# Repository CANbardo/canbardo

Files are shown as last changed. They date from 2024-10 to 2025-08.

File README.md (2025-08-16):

# CANbardo

CANbardo is an open hardware Universal Serial Bus (USB) to Controller
Area Network (CAN) adapter board. It is designed to be compatible with
the open source
[CANnectivity](https://github.com/CANnectivity/cannectivity) firmware.

CANbardo is licensed under the [CERN-OHL-P-2.0 license](LICENSE).

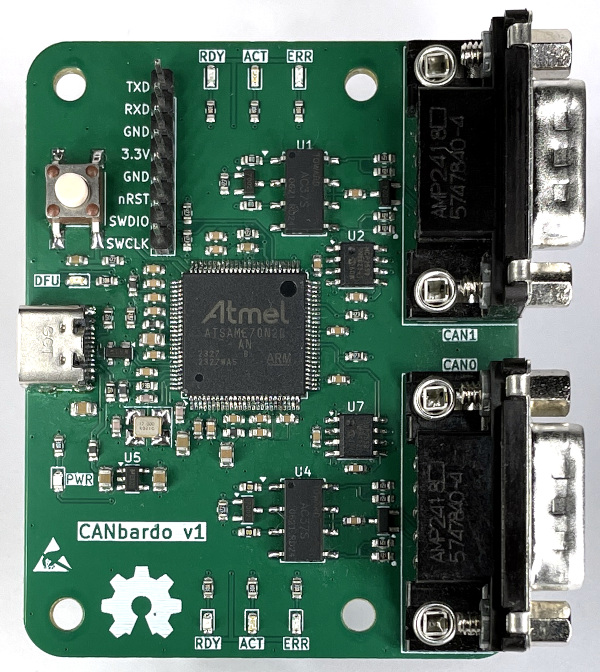
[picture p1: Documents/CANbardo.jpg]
CANbardo


## Hardware Features

The CANbardo board provides the following features:

- Atmel SAME70N20B microcontroller
- 12 MHz 10 ppm crystal
- CAN classic support
- CAN FD (flexible data rate) support
- Fast-speed and Hi-speed USB 2.0 support (USB-C connector)
- Two independent CAN channels (DB-9M connectors)
- 2 x GPIO-controlled MCP2558FD CAN transceivers
- 2 x GPIO-controlled 120 ohm CAN bus termination resistors
- GPIO-controlled LEDs:
  - 2 x CAN channel state LEDs (green)
  - 2 x CAN channel activity LEDs (yellow)
  - 2 x CAN channel error LEDs (red)
  - 1 x Device Firmware Upgrade (DFU) LED (yellow)
- Power LED (green)
- Device Firmware Upgrade (DFU) push button
- Serial Wire Debug (SWD) and UART (3V3) available on header

## Firmware Support

The CANbardo board is supported by the following firmware:

- [Zephyr RTOS](https://docs.zephyrproject.org/latest/boards/others/canbardo/doc/index.html)
- [CANnectivity](https://github.com/CANnectivity/cannectivity)

## Enclosure

An [OpenSCAD](https://openscad.org) model for an acyllic enclosure is
available under the [Enclosure](Enclosure) folder. This model is
designed to laser cut in 2 mm clear acrylic plates and fitted to the
CANbardo board using eight M3x6 BH insex screws and four M3x8 threaded
standoffs.

## Design Documentation

The following design documentation is available:

- [Schematic](Documents/CANbardo_Schematic.pdf)
- [Layout](Documents/CANbardo-Layout.pdf)
- [3D model](Documents/CANbardo.step)
- [KiCad files](Kicad_8_files)
- [Fabrication files](Fabrication_files)
- [3D view](Documents/3D_view.png)
- [Enclosure](Enclosure)

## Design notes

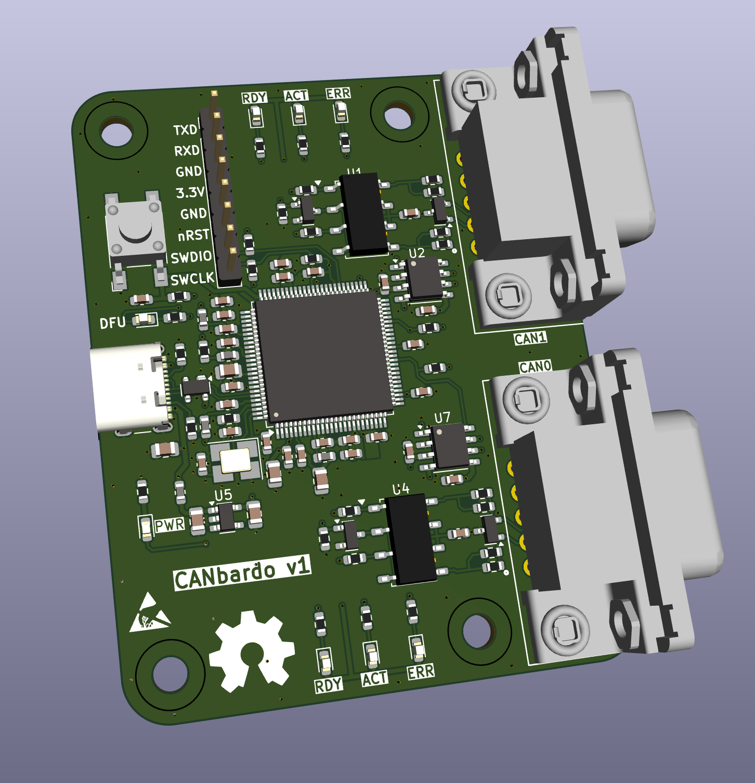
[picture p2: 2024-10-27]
Documents/3D_view.png

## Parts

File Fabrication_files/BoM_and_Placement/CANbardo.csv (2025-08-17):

Id | Designator | Footprint | Quantity | Designation | Supplier and ref
1 | C12,C14,C6 | C_0603_1608Metric | 3 | 10p
2 | J1 | USB_C_Receptacle_GCT_USB4105-xx-A_16P_TopMnt_Horizontal | 1 | USB_C_Receptacle_USB2.0
3 | J5 | PinHeader_1x08_P2.54mm_Vertical_zigzag | 1 | Conn_01x08_Pin
4 | R5,R11,R12 | R_0603_1608Metric | 3 | 2.7k
5 | R13,R16,R32 | R_0603_1608Metric | 3 | 390R
6 | R14,R19 | R_0603_1608Metric | 2 | 620R
7 | R15,R1,R9,R18 | R_0603_1608Metric | 4 | 4.7k
8 | U1,U4 | SOP-8GW_4.4x9.4mm_P2.54mm | 2 | AC37S
9 | C24,C33,C25,C18,C31,C7,C8,C22,C11,C23,C4,C20,C13,C17,C9,C21,C32,C26,C1,C19,C28,C29 | C_0603_1608Metric | 22 | 100n
10 | C5,C3,C2,C30 | C_0805_2012Metric | 4 | 1u
11 | R24,R22,R23,R20,R28,R26,R25,R27 | R_0603_1608Metric | 8 | 120R
12 | R2,R7,R6,R10 | R_0603_1608Metric | 4 | 47k
13 | FB4,FB5,FB3,FB2 | L_0603_1608Metric | 4 | blm18pg471sn1
14 | C16,C15 | C_0805_2012Metric | 2 | 4.7u
15 | D3,D10,D6 | LED_0603_1608Metric | 3 | LED 0603 Yellow
16 | R8,R17,R21,R29 | R_0603_1608Metric | 4 | 1k
17 | U5 | SOT-23-5 | 1 | AP2112K-3.3
18 | Q2,Q1 | SOT-23 | 2 | 2N7002
19 | D1,D5,D2 | LED_0603_1608Metric | 3 | LED 0603 Green
20 | D9,D8 | SOT-23 | 2 | NUP2105L
21 | C27,C10 | C_0603_1608Metric | 2 | 47n
22 | R3,R4 | R_0603_1608Metric | 2 | 5.1k
23 | J4,J3 | CONN9_5747840-4_TEC | 2 | DE9_Plug_MountingHoles
24 | R30 | R_0603_1608Metric | 1 | 5.62k
25 | R31 | R_0603_1608Metric | 1 | 2.2R
26 | SW1 | SW_SMD_Tactile_4pin | 1 | FSM4JSMAATR.
27 | FB1 | L_0603_1608Metric | 1 | 120@100MHz
28 | D4,D7 | LED_0603_1608Metric | 2 | LED 0603 Red
29 | Y1 | Crystal_SMD_3225-4Pin_3.2x2.5mm_HandSoldering | 1 | LFXTAL054208RL3K
30 | U2,U7 | SOIC-8_3.9x4.9mm_P1.27mm | 2 | MCP2558FD-xSN
31 | U13 | LQFP-100_14x14mm_P0.5mm | 1 | ATSAME70N20B-AN
32 | D11 | SOT-143 | 1 | PRTR5V0U2X

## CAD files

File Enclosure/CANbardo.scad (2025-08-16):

// Rendering
$fn = 100;

// Plate thickness
thickness = 2;

module plate(screw_d = 3.5) {
    width = 56;
    height = 70;
    rounding = 5;

    difference() {
        translate([rounding, rounding, 0]) {
            minkowski() {
                square(size = [width - 2 * rounding, height - 2 * rounding], center = false);
                circle(r = rounding);
            }
        }

        /* Screw holes */
        for (x = [5, 38]) {
            for (y = [5, 65]) {
                offset_x = x;
                offset_y = y;
                translate([offset_x, offset_y, 0]) {
                    circle(d = screw_d);
                }
            }
        }
    }
}

module plate_bottom() {
    rounding = 1;

    difference() {
        plate();

        /* DB-9M connector shield solder pads */
        for (y = [4, 29, 41, 66]) {
            translate([46.5, y, 0]) {
                circle(d = 5);
            }
        }

        /* DB-9M connector pin solder pads */
        for (y = [11, 48]) {
            translate([45.5 - rounding, y - rounding, 0]) {
                minkowski() {
                    square(size = [6 - 2 * rounding, 15 - 2 * rounding], center = false);
                    circle(r = rounding);
                }
            }
        }

        /* Pin header solder pads */
        translate([16.25 - rounding, 47 - rounding, 0]) {
            minkowski() {
                square(size = [3 - 2 * rounding, 22 - 2 * rounding], center = false);
                circle(r = rounding);
            }
        }
    }
}

module plate_bottom_3d() {
    linear_extrude(height = thickness) {
        plate_bottom();
    }
}

module plate_top() {
    rounding = 1;

    difference() {
        plate();

        /* DFU button */
        translate([6, 52, 0]) {
            circle(d = 4);
        }

        /* DB-9M connectors */
        for (y = [16.5, 53.5]) {
            translate([50, y, 0]) {
                square([13, 18], center = true);
            }
            translate([55, y, 0]) {
                square([12, 33], center = true);
            }
        }

        /* Pin header */
        translate([16.25 - rounding, 47 - rounding, 0]) {
            minkowski() {
                square(size = [3 - 2 * rounding, 22 - 2 * rounding], center = false);
                circle(r = rounding);
            }
        }
    }
}

module plate_top_3d() {
    linear_extrude(height = thickness) {
        plate_top();
    }
}

module model_2d() {
    plate_bottom();

    translate([60, 0, 0]) {
        plate_top();
    }
}

module model_3d() {
    import("CANbardo.stl");

    translate([0, 0, -1 * thickness]) {
        %plate_bottom_3d();
    }

    translate([0, 0, 1.6 + 6]) {
        %plate_top_3d();
    }
}

3d = $preview;

if (3d) {
    model_3d();
} else {
    model_2d();
}

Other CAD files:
Enclosure/CANbardo.dxf

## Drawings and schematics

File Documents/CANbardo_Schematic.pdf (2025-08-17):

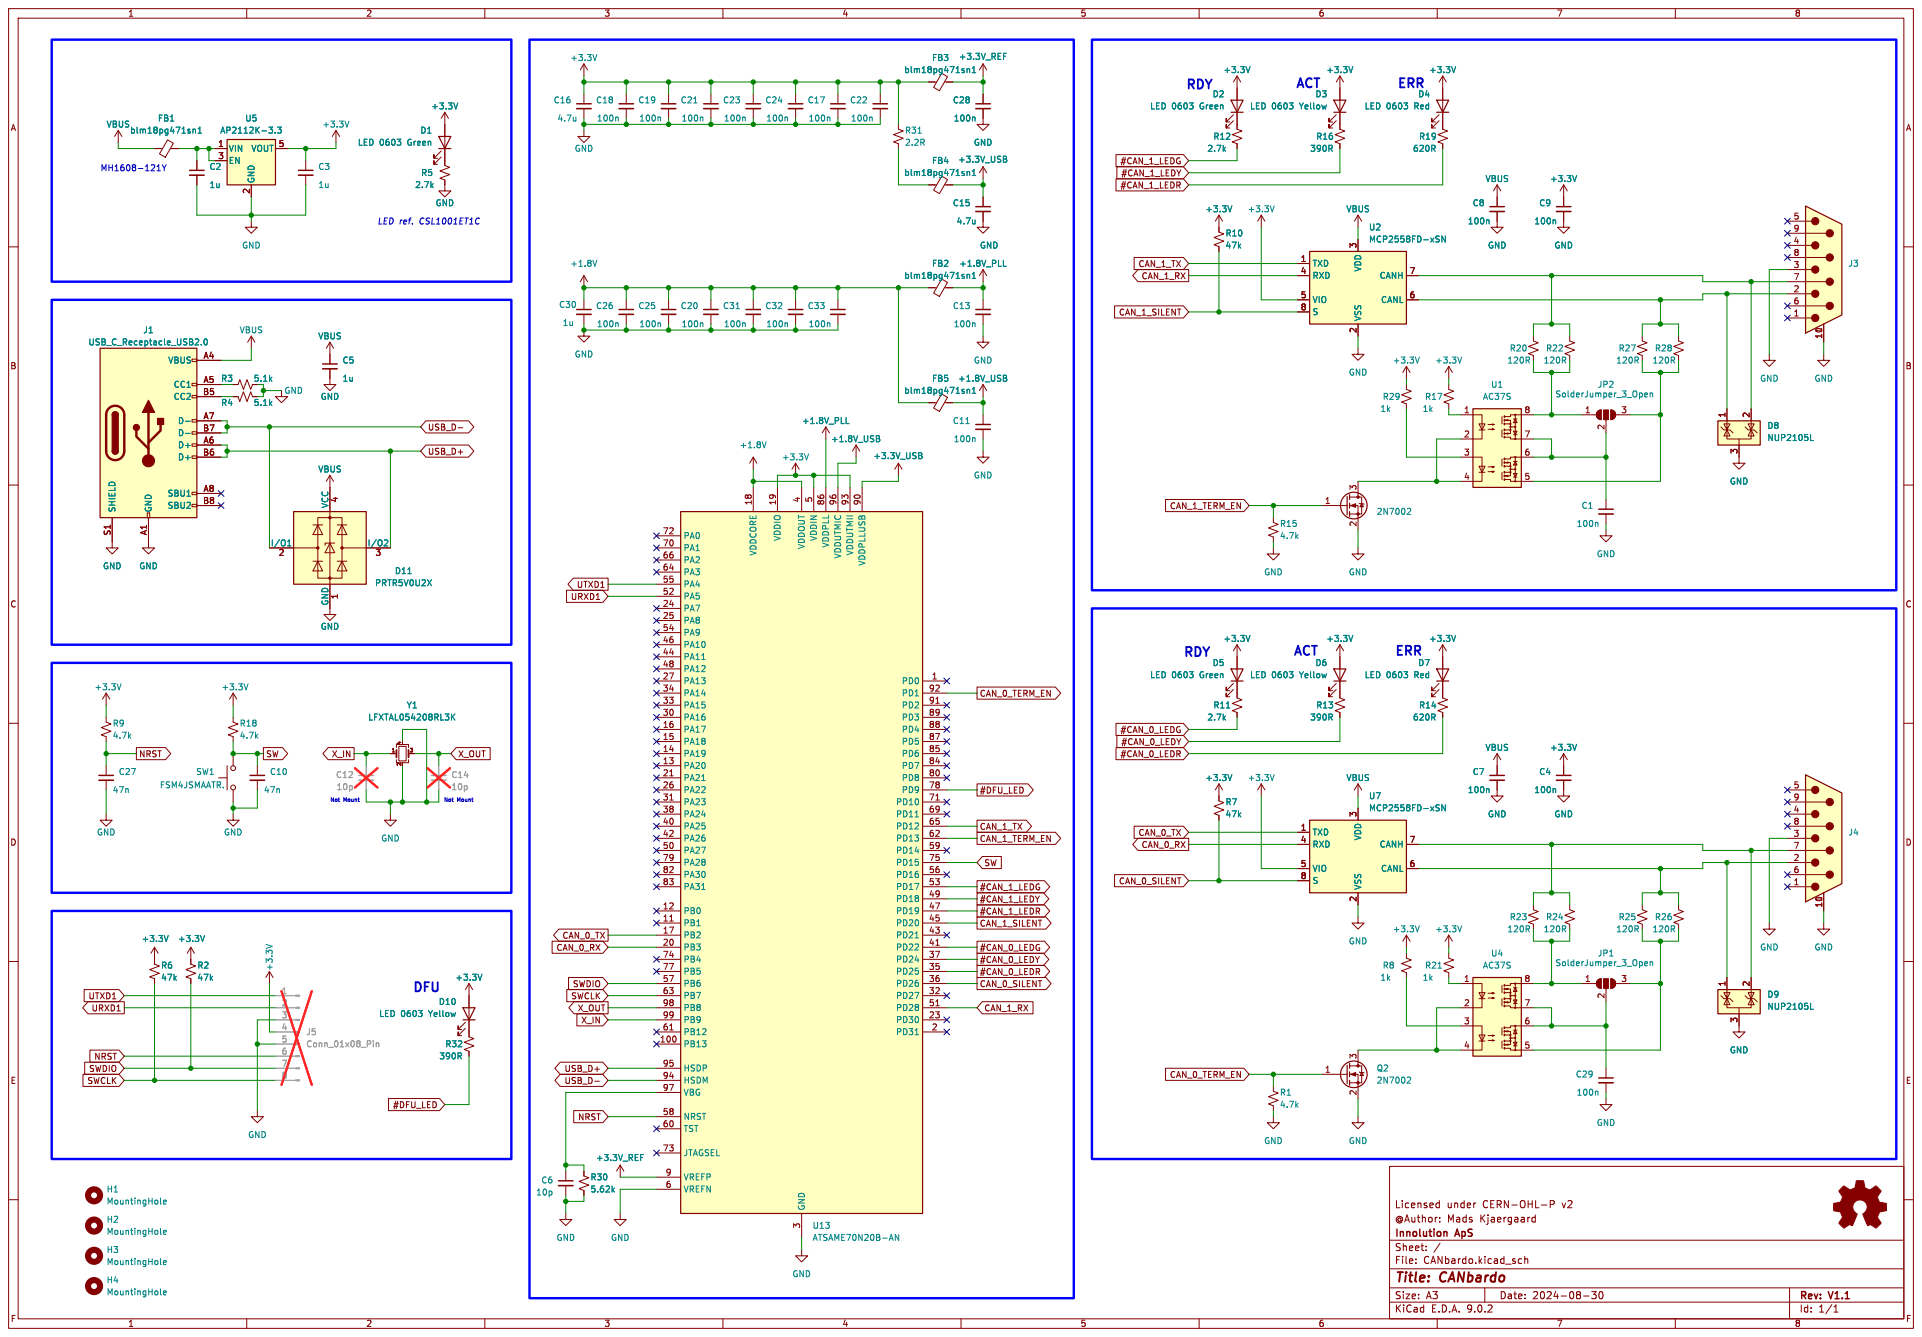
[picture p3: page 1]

PA0 72 PA1 70 PA2 66 PA3 64 PA4 55 PA5 52 PA7 24 PA8 25 PA9 54 PA10 46 PA11 44 PA12 48 PA13 27 PA14 34 PA15 33 PA16 30 PA17 16 PA18 15 PA19 14 PA20 13 PA21 21 PA22 26 PA23 31 PA24 38 PA25 40 PA26 42 PA27 50 PA28 79 PA30 82 PA31 83 PB0 12 PB1 11 PB2 17 PB3 20 PB4 74 PB5 77 PB6 57 PB7 63 PB8 98 PB9 99 PB12 61 PB13 100 HSDP 95 HSDM 94 VBG 97 NRST 58 TST 60

5 VDDPLL 86 VDDUTMIC 96 VDDUTMII 93 VDDPLLUSB 90 PD0 1 PD1 92 PD2 91 PD3 89 PD4 88 PD5 87 PD6 85 PD7 84 PD8 80 PD9 78 PD10 71 PD11 69 PD12 65 PD13 62 PD14 59 PD15 75 PD16 56 PD17 53 PD18 49 PD19 47 PD20 45 PD21 43 PD22 41 PD24 37 PD25 35 PD26 36 PD27 32 PD28 51 PD30 23 PD31 2 U13 ATSAME70N20B-AN

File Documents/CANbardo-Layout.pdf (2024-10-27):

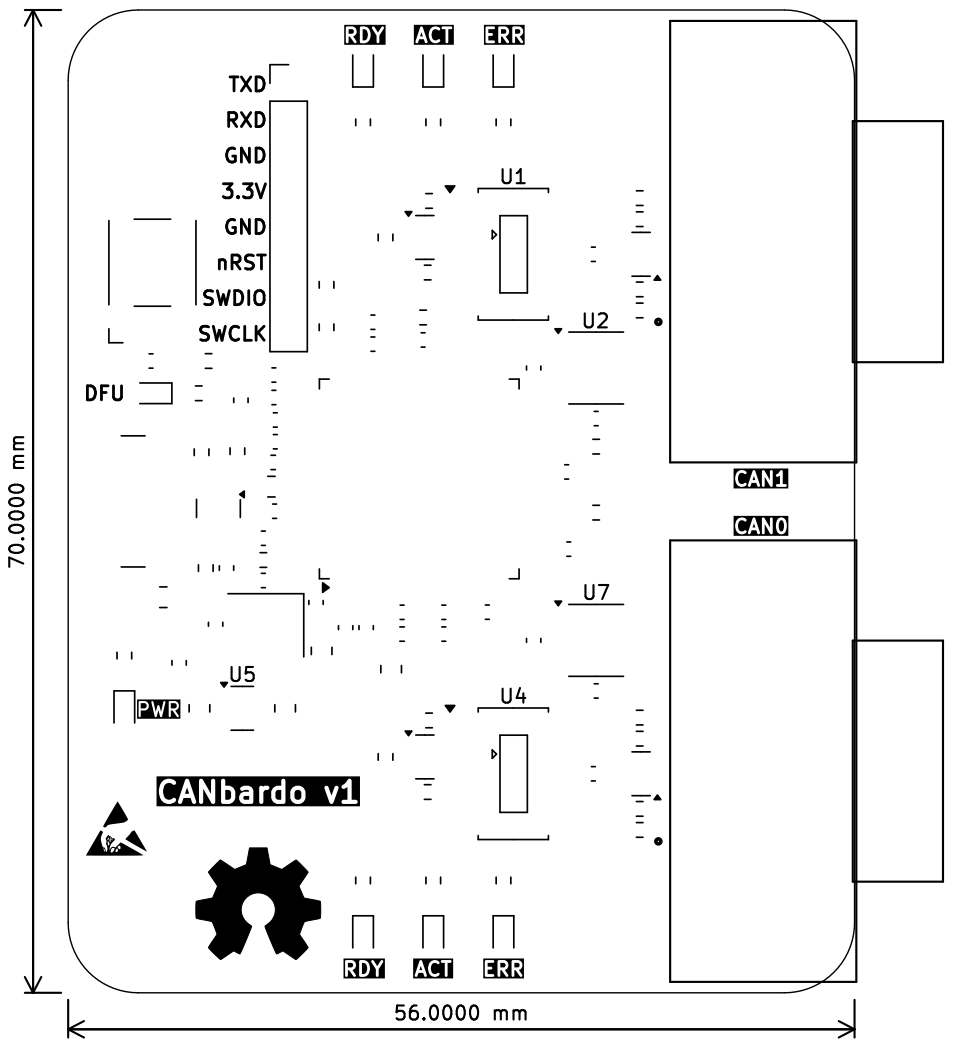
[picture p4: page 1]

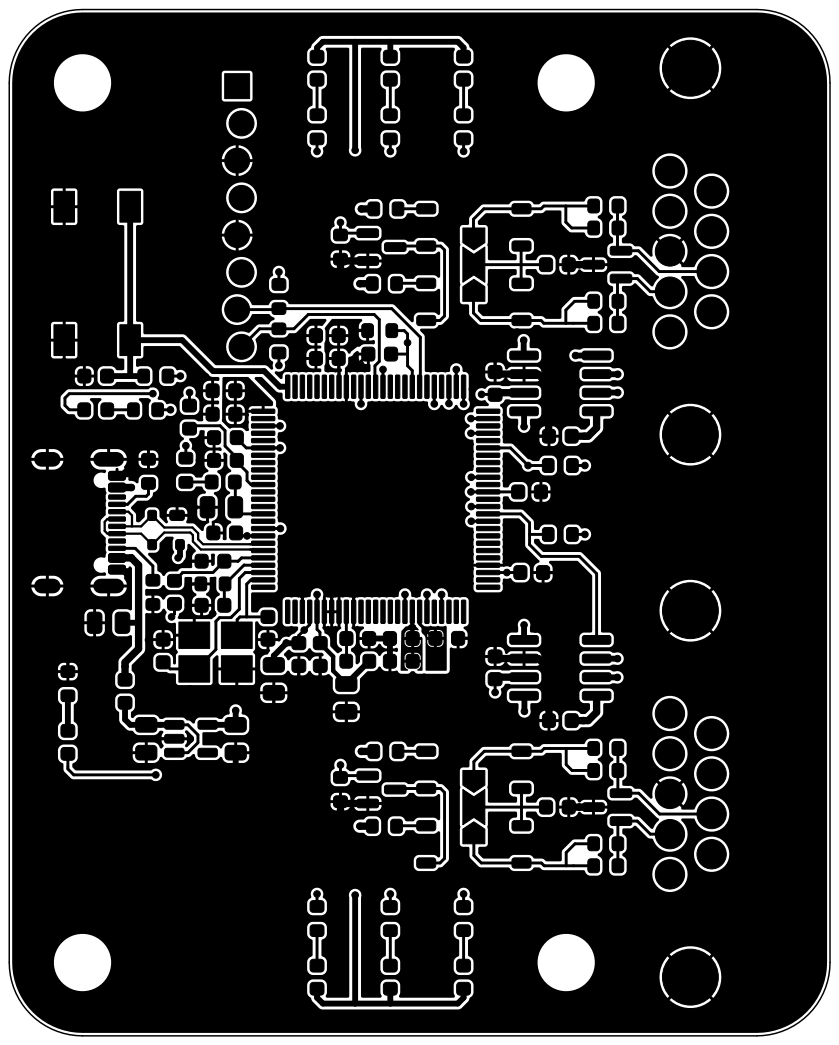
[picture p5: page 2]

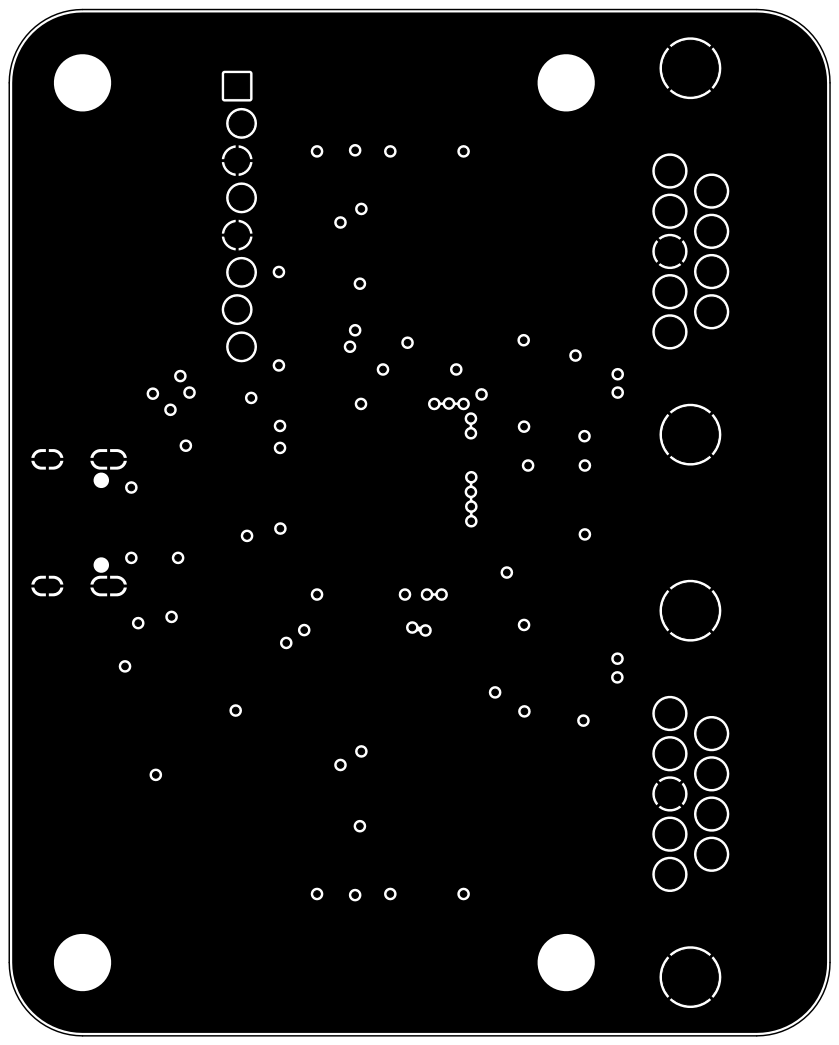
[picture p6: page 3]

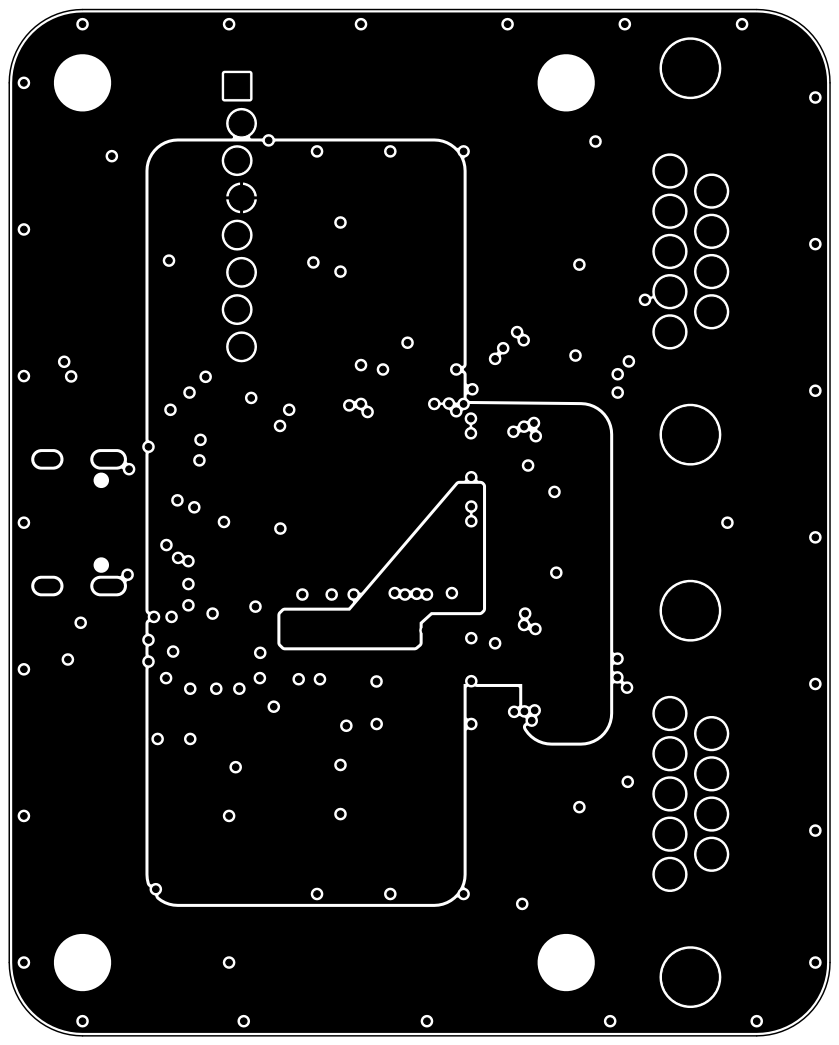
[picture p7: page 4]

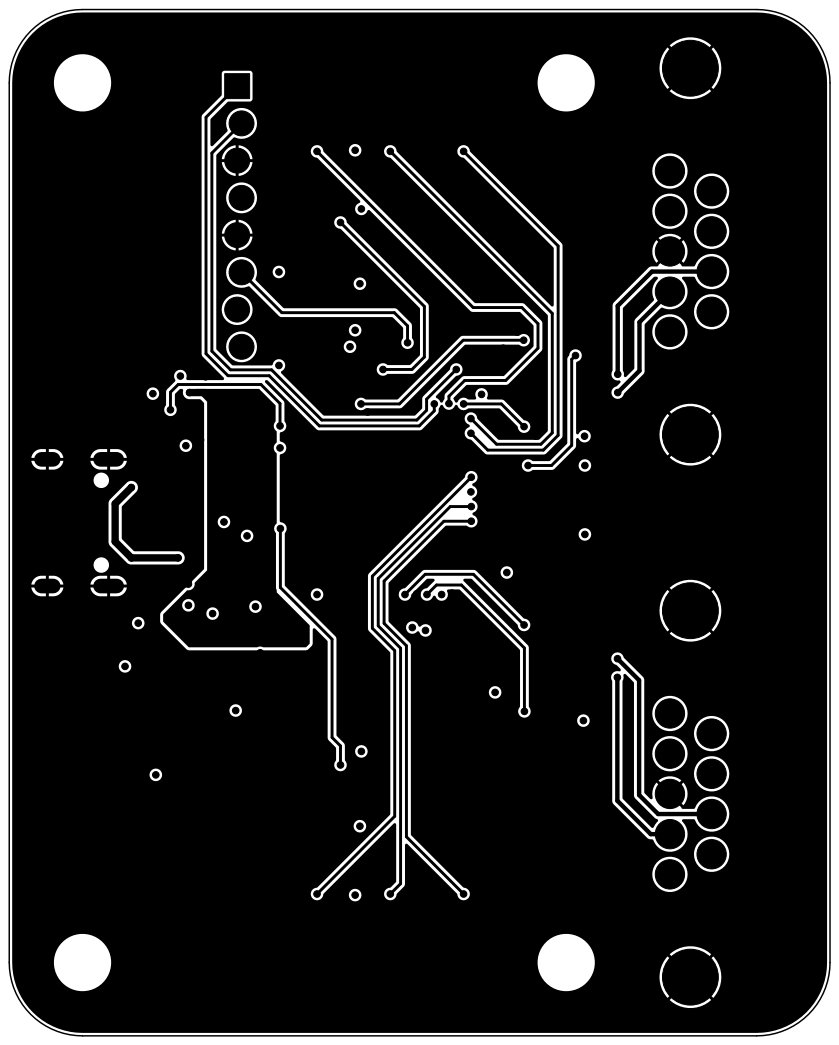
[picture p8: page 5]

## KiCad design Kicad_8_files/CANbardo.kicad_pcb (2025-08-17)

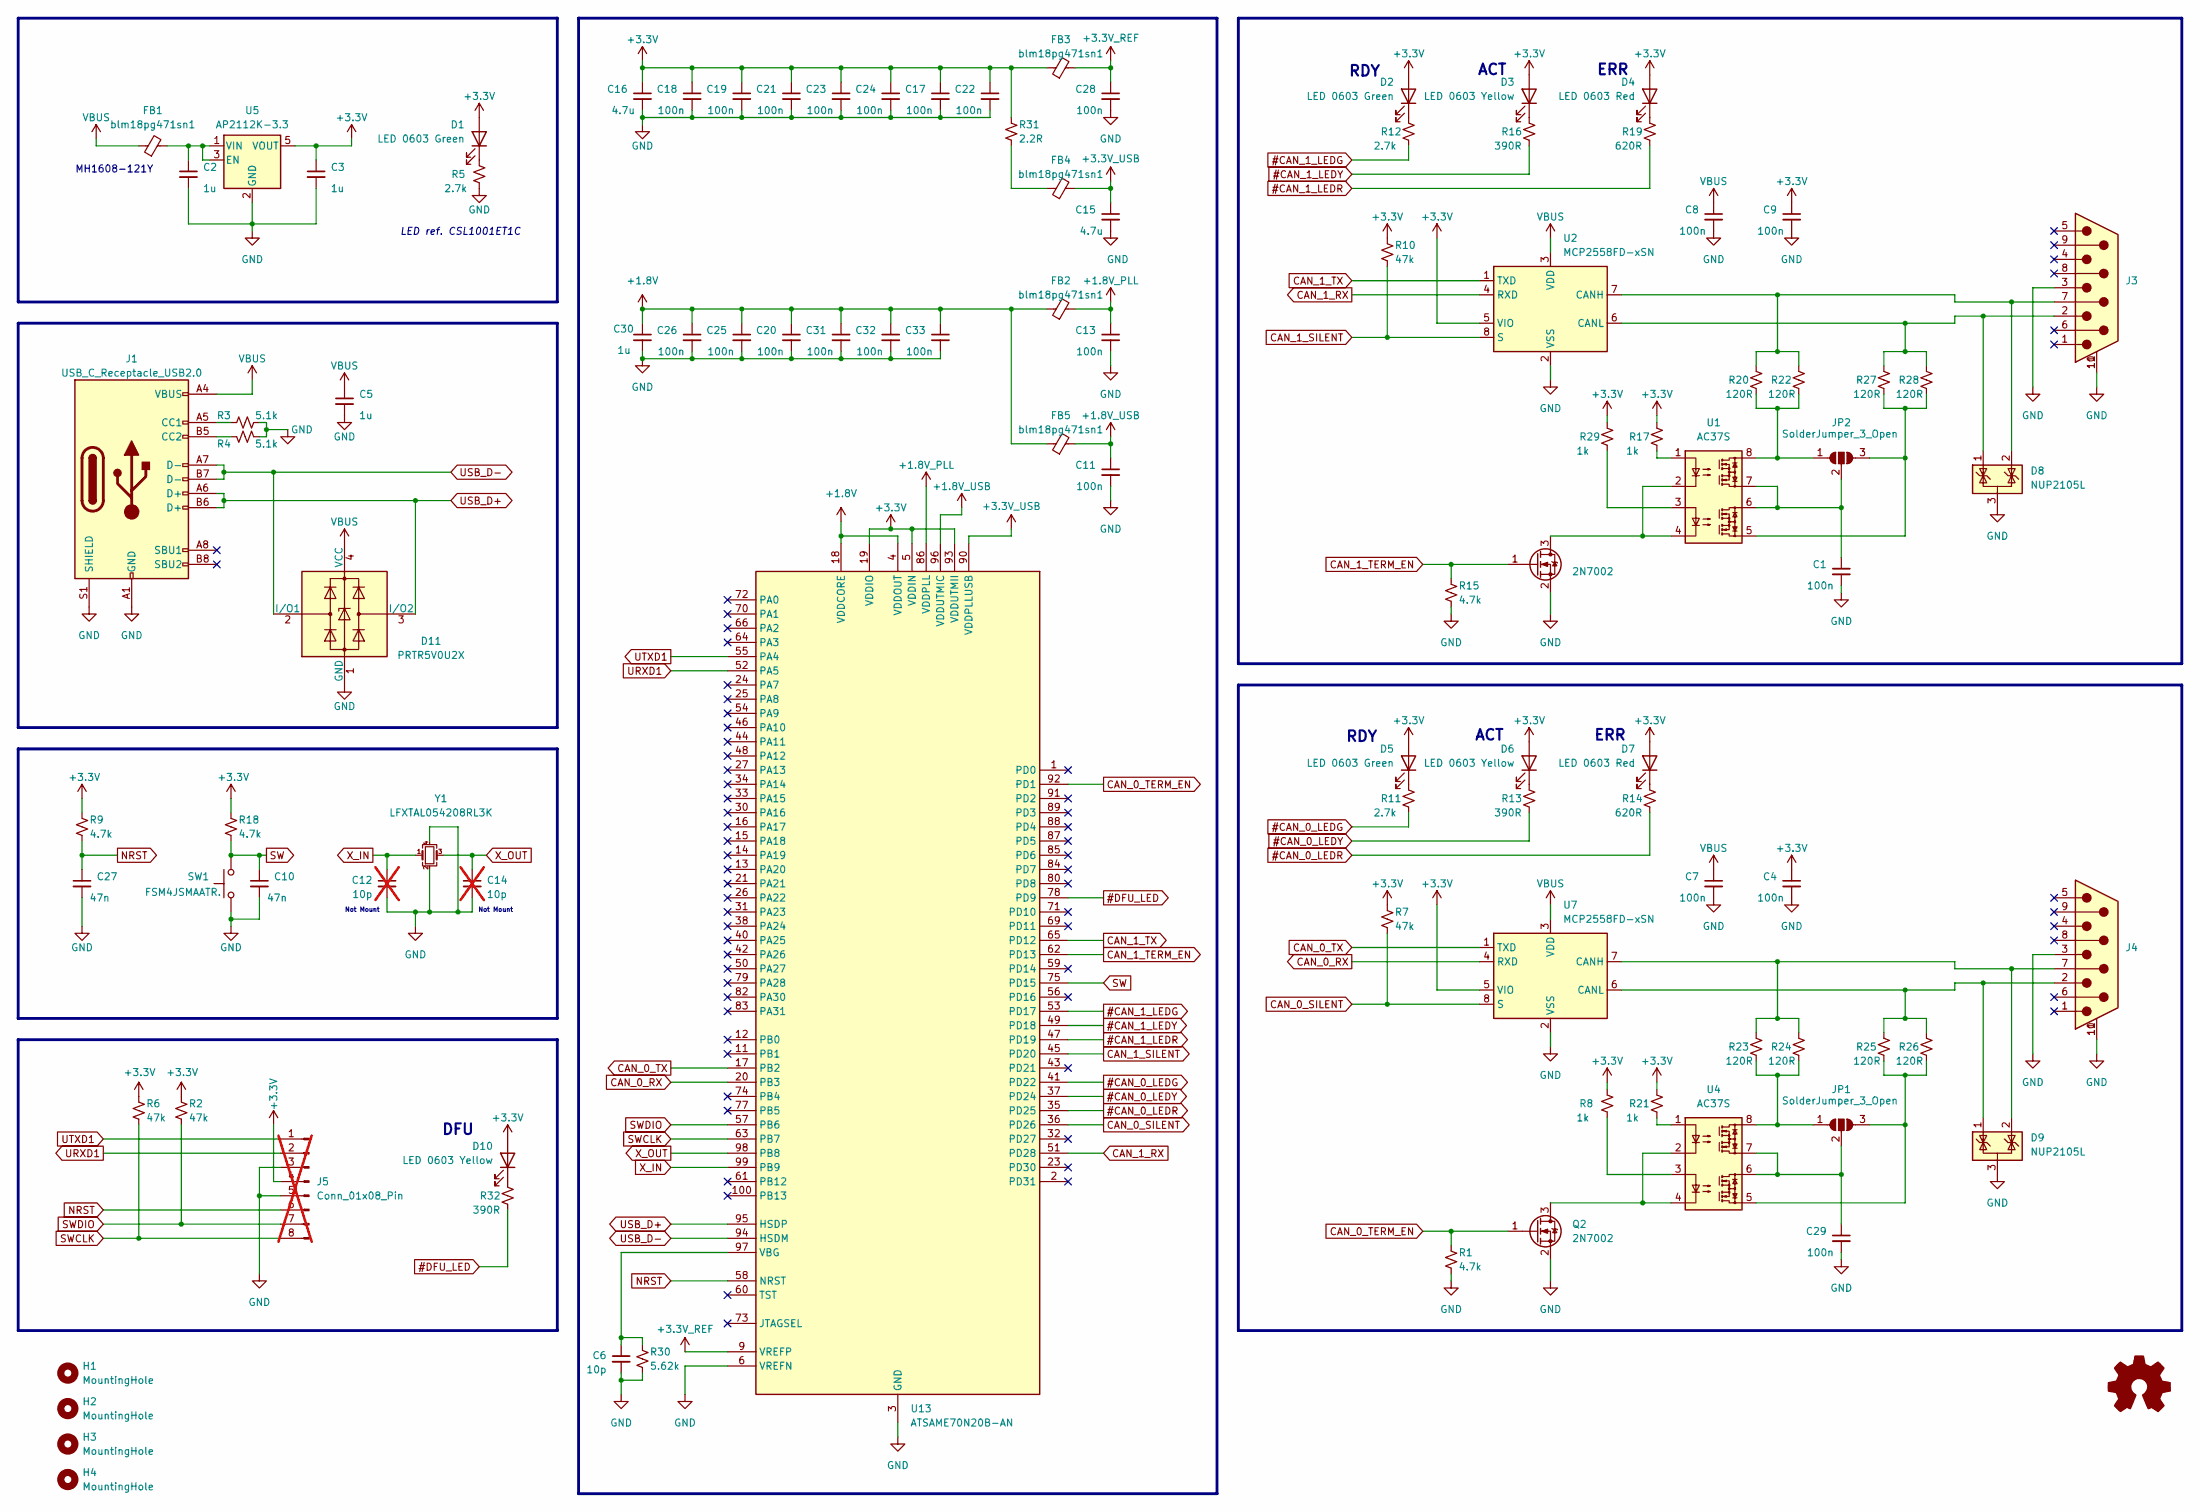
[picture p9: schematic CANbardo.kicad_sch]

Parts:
C1, C4, C7, C8, C9, C11, C13, C17, C18, C19, C20, C21, C22, C23, C24, C25, C26, C28, C29, C31, C32, C33: 100n; C_0603_1608Metric
C2, C3, C5, C30: 1u; C_0805_2012Metric
C6: 10p; C_0603_1608Metric
C10, C27: 47n; C_0603_1608Metric
C12, C14: 10p; C_0603_1608Metric; not fitted
C15, C16: 4.7u; C_0805_2012Metric
D1, D2, D5: LED 0603 Green; LED_0603_1608Metric
D3, D6, D10: LED 0603 Yellow; LED_0603_1608Metric
D4, D7: LED 0603 Red; LED_0603_1608Metric
D8, D9: NUP2105L; SOT-23
D11: PRTR5V0U2X; SOT-143
FB1, FB2, FB3, FB4, FB5: blm18pg471sn1; L_0603_1608Metric
H1, H2, H3, H4: MountingHole; MountingHole_3.5mm
J1: USB_C_Receptacle_USB2.0; USB_C_Receptacle_GCT_USB4105-xx-A_16P_TopMnt_Horizontal
J3, J4: DE9_Plug_MountingHoles; CONN9_5747840-4_TEC
J5: Conn_01x08_Pin; PinHeader_1x08_P2.54mm_Vertical_zigzag; not fitted
JP1, JP2: SolderJumper_3_Open; SolderJumper-3_P2.0mm_Open_TrianglePad1.0x1.5mm
LOGO1: Logo_Open_Hardware_Small; OSHW-Symbol_8.9x8mm_SilkScreen
Q1, Q2: 2N7002; SOT-23
R1, R9, R15, R18: 4.7k; R_0603_1608Metric
R2, R6, R7, R10: 47k; R_0603_1608Metric
R3, R4: 5.1k; R_0603_1608Metric
R5, R11, R12: 2.7k; R_0603_1608Metric
R8, R17, R21, R29: 1k; R_0603_1608Metric
R13, R16, R32: 390R; R_0603_1608Metric
R14, R19: 620R; R_0603_1608Metric
R20, R22, R23, R24, R25, R26, R27, R28: 120R; R_0603_1608Metric
R30: 5.62k; R_0603_1608Metric
R31: 2.2R; R_0603_1608Metric
SW1: FSM4JSMAATR.; SW_SMD_Tactile_4pin
U1, U4: AC37S; SOP-8GW_4.4x9.4mm_P2.54mm
U2, U7: MCP2558FD-xSN; SOIC-8_3.9x4.9mm_P1.27mm
U5: AP2112K-3.3; SOT-23-5
U13: ATSAME70N20B-AN; LQFP-100_14x14mm_P0.5mm
Y1: LFXTAL054208RL3K; Crystal_SMD_3225-4Pin_3.2x2.5mm_HandSoldering

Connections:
#CAN_0_LEDG: R11.2, U13.41 (PD22)
#CAN_0_LEDR: R14.2, U13.35 (PD25)
#CAN_0_LEDY: R13.2, U13.37 (PD24)
#CAN_1_LEDG: R12.2, U13.53 (PD17)
#CAN_1_LEDR: R19.2, U13.47 (PD19)
#CAN_1_LEDY: R16.2, U13.49 (PD18)
#DFU_LED: R32.2, U13.78 (PD9)
+1.8V: C20.1, C25.1, C26.1, C30.1, C31.1, C32.1, C33.1, FB2.1, FB5.1, U13.4 (VDDOUT), U13.18 (VDDCORE), U13.22 (VDDCORE), U13.39 (VDDCORE), U13.76 (VDDCORE)
+1.8V_PLL: C13.1, FB2.2, U13.86 (VDDPLL)
+1.8V_USB: C11.1, FB5.2, U13.96 (VDDUTMIC)
+3.3V: C3.1, C4.1, C9.1, C16.1, C17.1, C18.1, C19.1, C21.1, C22.1, C23.1, C24.1, D1.2 (A), D2.2 (A), D3.2 (A), D4.2 (A), D5.2 (A), D6.2 (A), D7.2 (A), D10.2 (A), FB3.1, J5.4, R2.1, R6.1, R7.1, R8.1, R9.1, R10.1, R17.1, R18.1, R21.1, R29.1, R31.1, U2.5 (VIO), U5.5 (VOUT), U7.5 (VIO), U13.5 (VDDIN), U13.19 (VDDIO), U13.28 (VDDIO), U13.68 (VDDIO), U13.81 (VDDIO), U13.93 (VDDUTMII)
+3.3V_REF: C28.1, FB3.2, U13.9 (VREFP)
+3.3V_USB: C15.1, FB4.2, U13.90 (VDDPLLUSB)
CAN_0_RX: U7.4 (RXD), U13.20 (PB3)
CAN_0_SILENT: R7.2, U7.8 (S), U13.36 (PD26)
CAN_0_TERM_EN: Q2.1 (G), R1.1, U13.92 (PD1)
CAN_0_TX: U7.1 (TXD), U13.17 (PB2)
CAN_1_RX: U2.4 (RXD), U13.51 (PD28)
CAN_1_SILENT: R10.2, U2.8 (S), U13.45 (PD20)
CAN_1_TERM_EN: Q1.1 (G), R15.1, U13.62 (PD13)
CAN_1_TX: U2.1 (TXD), U13.65 (PD12)
GND: C1.2, C2.2, C3.2, C4.2, C5.2, C6.2, C7.2, C8.2, C9.2, C10.2, C11.2, C12.2, C13.2, C14.2, C15.2, C16.2, C17.2, C18.2, C19.2, C20.2, C21.2, C22.2, C23.2, C24.2, C25.2, C26.2, C27.2, C28.2, C29.2, C30.2, C31.2, C32.2, C33.2, D8.3 (A), D9.3 (A), D11.1 (GND), J1.A1 (GND), J1.A12 (GND), J1.B1 (GND), J1.B12 (GND), J1.S1 (SHIELD), J3.3, J3.10 (PAD), J3.11 (PAD), J4.3, J4.10 (PAD), J4.11 (PAD), J5.3, J5.5, Q1.2 (S), Q2.2 (S), R1.2, R3.2, R4.2, R5.2, R15.2, R30.2, SW1.1, U2.2 (VSS), U5.2 (GND), U7.2 (VSS), U13.3 (GND), U13.6 (VREFN), U13.7 (GND), U13.8 (GND), U13.10 (GND), U13.29 (GND), U13.67 (GND), Y1.2, Y1.4
NRST: C27.1, J5.6, R9.2, U13.58 (NRST)
unnamed: D1.1 (K), R5.1
unnamed: D2.1 (K), R12.1
unnamed: D3.1 (K), R16.1
unnamed: D4.1 (K), R19.1
unnamed: D5.1 (K), R11.1
unnamed: D6.1 (K), R13.1
unnamed: D7.1 (K), R14.1
unnamed: D10.1 (K), R32.1
unnamed: FB4.1, R31.2
unnamed: J1.A5 (CC1), R3.1
unnamed: J1.B5 (CC2), R4.1
unnamed: JP1.1 (A), R23.2, R24.2, U4.8
unnamed: JP1.3 (B), R25.2, R26.2, U4.5
unnamed: C29.1, JP1.2 (C), U4.6, U4.7
unnamed: JP2.1 (A), R20.2, R22.2, U1.8
unnamed: JP2.3 (B), R27.2, R28.2, U1.5
unnamed: C1.1, JP2.2 (C), U1.6, U1.7
unnamed: Q1.3 (D), U1.2, U1.4
unnamed: Q2.3 (D), U4.2, U4.4
unnamed: R8.2, U4.3
unnamed: R17.2, U1.1
unnamed: R21.2, U4.1
unnamed: R29.2, U1.3
unnamed: D8.2 (K), J3.7, R20.1, R22.1, U2.7 (CANH)
unnamed: D8.1 (K), J3.2, R27.1, R28.1, U2.6 (CANL)
unnamed: C2.1, FB1.2, U5.1 (VIN), U5.3 (EN)
unnamed: D9.2 (K), J4.7, R23.1, R24.1, U7.7 (CANH)
unnamed: D9.1 (K), J4.2, R25.1, R26.1, U7.6 (CANL)
unnamed: C6.1, R30.1, U13.97 (VBG)
SW: C10.1, R18.2, SW1.2, U13.75 (PD15)
SWCLK: J5.8, R6.2, U13.63 (PB7)
SWDIO: J5.7, R2.2, U13.57 (PB6)
URXD1: J5.2, U13.52 (PA5)
USB_D+: D11.3 (I/O2), J1.A6 (D+), J1.B6 (D+), U13.95 (HSDP)
USB_D-: D11.2 (I/O1), J1.A7 (D-), J1.B7 (D-), U13.94 (HSDM)
UTXD1: J5.1, U13.55 (PA4)
VBUS: C5.1, C7.1, C8.1, D11.4 (VCC), FB1.1, J1.A4 (VBUS), J1.A9 (VBUS), J1.B4 (VBUS), J1.B9 (VBUS), U2.3 (VDD), U7.3 (VDD)
X_IN: C12.1, U13.99 (PB9), Y1.1
X_OUT: C14.1, U13.98 (PB8), Y1.3

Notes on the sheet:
LED ref. CSL1001ET1C
ACT
MH1608-121Y
RDY
Not Mount
DFU
ERR

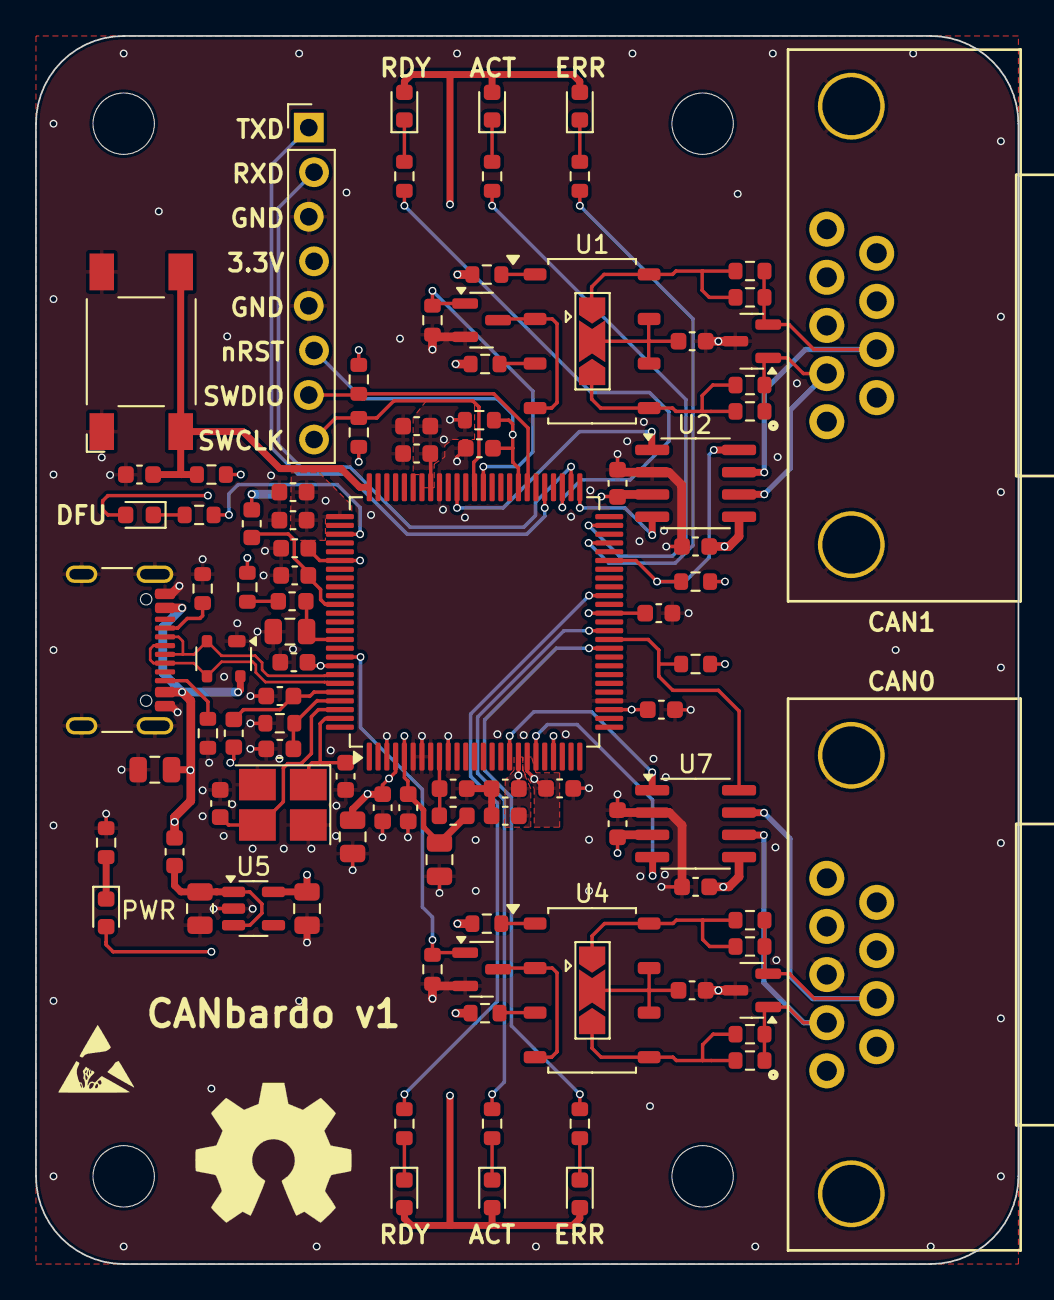
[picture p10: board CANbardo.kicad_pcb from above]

Board: 4 copper layers, 56.0 x 70.0 mm, 102 parts (0 on the bottom side), 62 nets.

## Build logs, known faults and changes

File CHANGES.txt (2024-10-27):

This is a summary of changes made to the CANbardo hardware for each release.

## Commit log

2024-10-27 Project v1
    Project upload
    Released version - v1
    [CANbardo-B_Cu.gbl, CANbardo-B_Mask.gbs, CANbardo-Edge_Cuts.gm1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]
2025-01-06 README: replace 3D view with photo of actual board
2025-08-16 enclosure: add OpenSCAD model for an acrylic enclosure
    Add an OpenSCAD model (and DXF export) for a simple acrylic enclosure.
    [CANbardo.dxf, CANbardo.scad]
2025-08-17 Updated LED resistors
    LED resistors updated to match intensity.
    Version updated from 1.0 to 1.1
    [CANbardo.csv, CANbardo.kicad_pcb, CANbardo.kicad_sch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]

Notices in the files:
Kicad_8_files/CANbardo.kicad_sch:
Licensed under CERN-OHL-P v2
